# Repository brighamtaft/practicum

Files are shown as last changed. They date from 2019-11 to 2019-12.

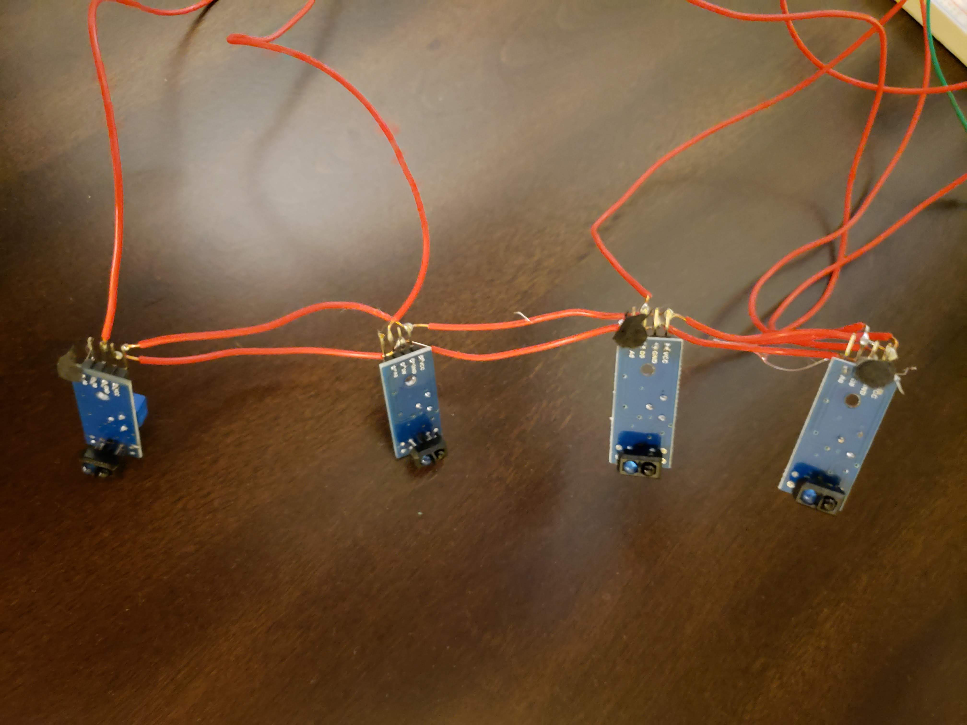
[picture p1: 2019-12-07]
sensors_prototype.jpg

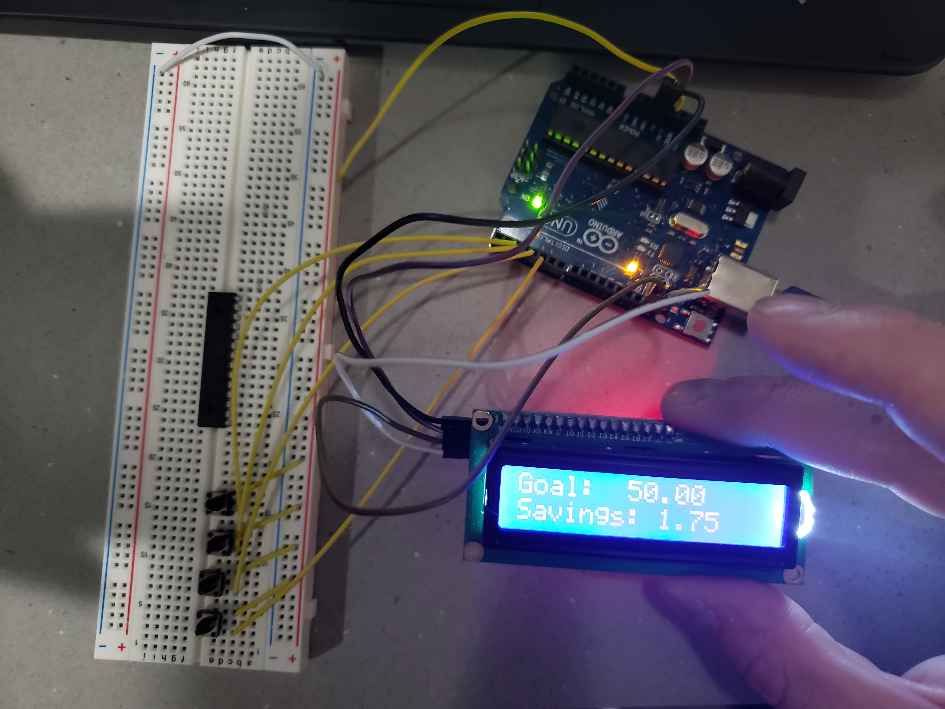
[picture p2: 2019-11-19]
prototype.jpg

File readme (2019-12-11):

(411RoughDraft.brd, 411RoughtDraft.sch) - status: complete - the 411roughDraft (.brd and .sch) are the original design files for our device. They are messy and error prone and do not hold any merit in the final design

(BOM.-Sheet1.pdf) - status: incomplete - Bill of Materials - has the appropriate quantity and compnents necessary for the PCB population but has yet to include the necessary materials needed for the container.

(BOM_Finalrev.xsl) - status complete - Bill of Materilas - up to date includes all necessary compoenents to be purchased.

(BankCode_rev1) - status: complete - The first complete rev for the arduino code used. Edit this to change the function of the microprocessor

(Child’s Piggy Bank.pptx) - status: incomplete - Presentation for final project that has in detail on what we did step by step 

(CointControllerV1.brd, CointControllerV1.sch) - status: complete - The complete schematic and brd layout for the device. Send the .brd file in to be printed.

(Coin Sort Face v5.stl, Coin Sort Ramp v5.stl) - status: complete but untested. These files have the same dimensions as the laser cut acrylic sorter and should work but have not been 3d printed and tested.

(TestPlan.pdf) - status: assignment comp[lete - test documentation with descriptions. Minimal test case in accordance with the assignment.

(Coin Sorter (Sized) v1.f3d) - status: complete but untested. This is a working 3D CAD file for fusion 360. It has been optimized to use minimum material and fit in a small print bed. It will require extensive supports to print with SLA style printer and would be recommended to split at the intersection of the ramp before printing in that style 3D printer.

(Design.pdf) - status: complete - basic block diagram of the basic functions of our device

(NextLevelDesign.pdf) - status: complete - a more detailed diagram of the functionality of our device

(PDS.docx) - status: complete - Product Design Specifications document

(ProjectBrainstorming.docx, Top.3.Ideas.docx) - status: complete - record of the project ideas for our group

(preliminarySchematicIMG.jfif, preliminarySchematic.sch) - status: complete - the very first incomplete basic schematic of device

(prototype.jpg) - status: complete - the first implemented device using buttons instead of sensors and an arduino

(testProcedure.docx) - status: incomplete - document describing the test procedure for the device

(T17 HW7 Test Plan.pdf) - status: complete - Homework based test plan.

(BetterSortV2.dxf) - status: Complete - Laser Printable file for acrylic coin sorter. Known to work with cast acrylic but not tested on other materials.

Programming instruction:
1) Flash the arduino bootloader onto the atmega328p. This can be done following the online tutorial found in this link: https://www.arduino.cc/en/Tutorial/ArduinoToBreadboard
2) Once the bootloader has been flashed you can solder the atmega328p to the board or insert it into a sleeve if you chose to purchase one.
3) Once the entire board is populated you can program the atmega328p with the BankCode_rev1 code. This can be done following the tutorial found at the same link as burning the bootloader. The difference in the connections is described below

Connections: (remember to remove the atmega328p from the arduinouno before programming)
  1) Arduino TX pin connects to pin5 of the 6x1 pin header
  2) Arduino RX pin connects to pin4 of the 6x1 pin header
  3) Arduino Vcc pin connects to pin2 of the 3x2 pin header
  4) Arduino gnd pin connects to pin6 of the 3x2 pin header
  5) Arduino reset pin connects to pin5 of the 3x2 pin header
  
 4) Once the wiring has been done upload the CoinCollector code to arduino as you normally would with the board selected being Arduino nano (atmega328p processor selected).
 5) The board should be ready to be wired up to the LCD screen and sensors. And you can begin the test procedure (see testProcedure.docx)

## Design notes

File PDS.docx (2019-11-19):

Product Design Specification (PDS)

Group 17

Brigham Webster

Jose Alvarez

Jens Evans

Sarah Mehler

Executive Summary / Concept of Operations

The Child’s Bank is a device that counts coins and displays the amount of money accrued. The bank is intended as a learning and motivation device for children, to help them keep track of how much money they have saved. To use the piggy bank, you put coins into the slot(s), and the bank automatically keeps a record of what has been entered.

Brief Market Analysis

The intended audience are parents who are interested in teaching their children about money. The competition would be conventional piggy banks. Our product is different because it not only helps children save money but also teaches them and is interactive. This will sell for about 20 dollars because the processing requirements are low which will require a simple chip. The device will also have a simple mechanical design for the coin storage that will be easily mass produced and batteries are sold separately.

Requirements

MUST

- Count coins (pennies, nickels, dimes, and quarters)
- Store Coins
- Be easy to use
- Display the amount of money that has been added in a clear and obvious way
- Use atmega328 processor
- Be PCB-based with 25% surface mount components

SHOULD

- Run on a battery
- Have an attractive enclosure
- Make the Mario coin sound when you insert a coin

MAY

- Sort coins
- Be able to set a goal
- Have a 3D printed animal-shaped enclosure

System Architecture

High Level Block Diagram

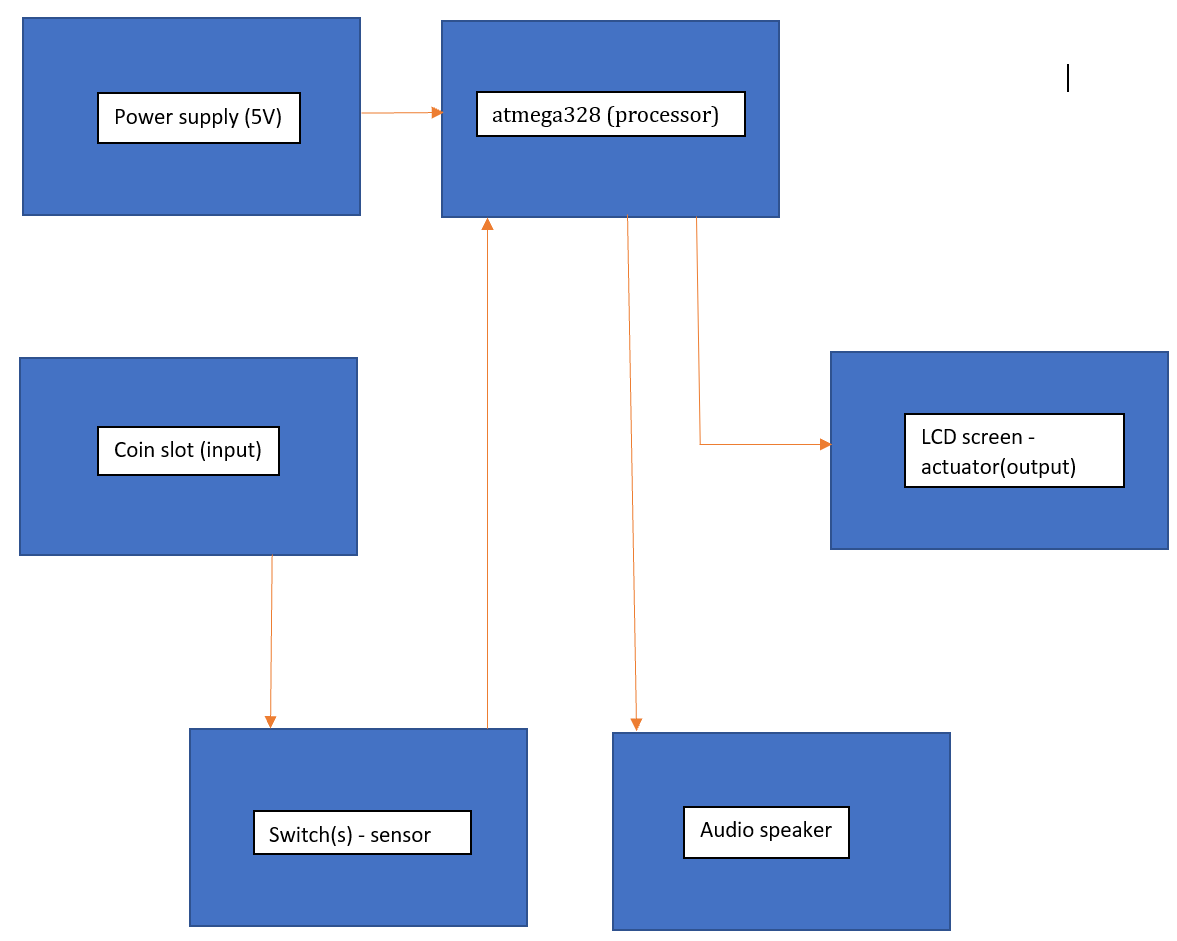
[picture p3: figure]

Design Specification

- The sensor will be a switch with enough sensitivity to be set by the weight of a coin.
- The processor will be an ATMEGA328
- The things that will be actuated are the inputs to the LCD screen
- The power supply will be about 5 Volts (Battery or USB)
- The mechanical design may be a wooden box with coin slots cut in and a lid to open it if we do not hit our must or may goals for a better box.
- We are going to use the Arduino development environment

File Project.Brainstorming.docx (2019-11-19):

Group 17

Sarah, Jose Alvarez, Jens, Brigham Webster

Brainstorming

1. Bike Computer (Speed or Cadence)
2. Electric Bike Motor
3. Hat that changes color for dancing at Rave******
4. Baby bottle temp sensor
5. Floating Business Card Holder****
6. Easy video game LED
7. Temperature sensor for phone (if it’s too hot or cold)
8. Timer you can set for how long you want to work (20 m, break, 20 m, etc.)
9. Cup thermometer tells you if coffee will burn your tongue****
10. Coin counter / piggy bank type device*****
11. Habit breaker
12. Habit MAKER / tracker
13. Fancy doorbell
14. Window security
15. Backup Beeper
16. Smart levelling device
17. Portable Charger
18. Short Range Transmitter Receiver
19. Wireless Morse Code Device
20. Optical Morse Code
21. Morse Code Decoder
22. Concussion Checker (Force for children)
23. Water bottle water measuring device
24. Wireless leash

Top 5 Ideas

Jens

1. Floating Business Card Holder (Levitating Magnet)
2. Piggy Bank
3. Electric Level
4. Bike Computer (Speed)
5. Device which can make any food

Brigham

1. Rave Hat
2. Seeing eye dog/backup car
3. Morse Code
4. Concussion Checker
5. Coin counter piggy bank

Sarah

1. Cup thermometer or baby bottle thermometer
2. Morse code device
3. Back up beeper
4. Coin counter / piggy bank
5. Level

Jose Alvarez

1. Portable charger
2. Morse code decoder
3. Wireless leash
4. Baby bottle temp sensor
5. Coin counter

Top 3 Ideas

1. Piggy Bank
2. Morse Code Decoder
3. Back up beeper

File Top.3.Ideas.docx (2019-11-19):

Practicum Top 3 Ideas

Group 17

Brigham, Sarah, Jens, Jose

1. Piggy Bank - group decided on the child's piggy bank for the practicum project

There will be different coin slots for quarters, dimes, nickels and pennies. Every time a coin is inserted into the appropriate slot a sensor will recognize this and count what has been inserted. An LCD display screen will display the current amount inside the bank which can be cleared/reset with a button. The atmega328 will control the LCD.

2. Morse Code Decoder

We will have a device that accepts input from a button in the form of morse code. The atmega328 will decode the morse and display it on an LCD screen.

3. Back up beeper

For cars that are outdated/not equipped with the back up rear view cameras or warning signals we will use a sensor that you can attach to the back of a car. It will produce a loud sound and light when the sensor gets within a certain range of an object. Additionally the light and sound frequency and intensity will increase as the sensor continues to move closer to an object. This is controlled by atmega328.

Conclusion: We chose the piggy bank because it sounded interesting to implement and had various challenges that all of has had not dealt with before. The piggy bank practicum idea can be easily divided into several components that can be easily split among the group. Additionally the piggy bank will not be so difficult that it would hinder our other lab projects and academic studies.

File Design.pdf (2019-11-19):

Brigham Webster
Jose Alvarez
Jens Evans
Sarah Muehler
Ece 411
Functional Decompposition

High Level Block Diagram

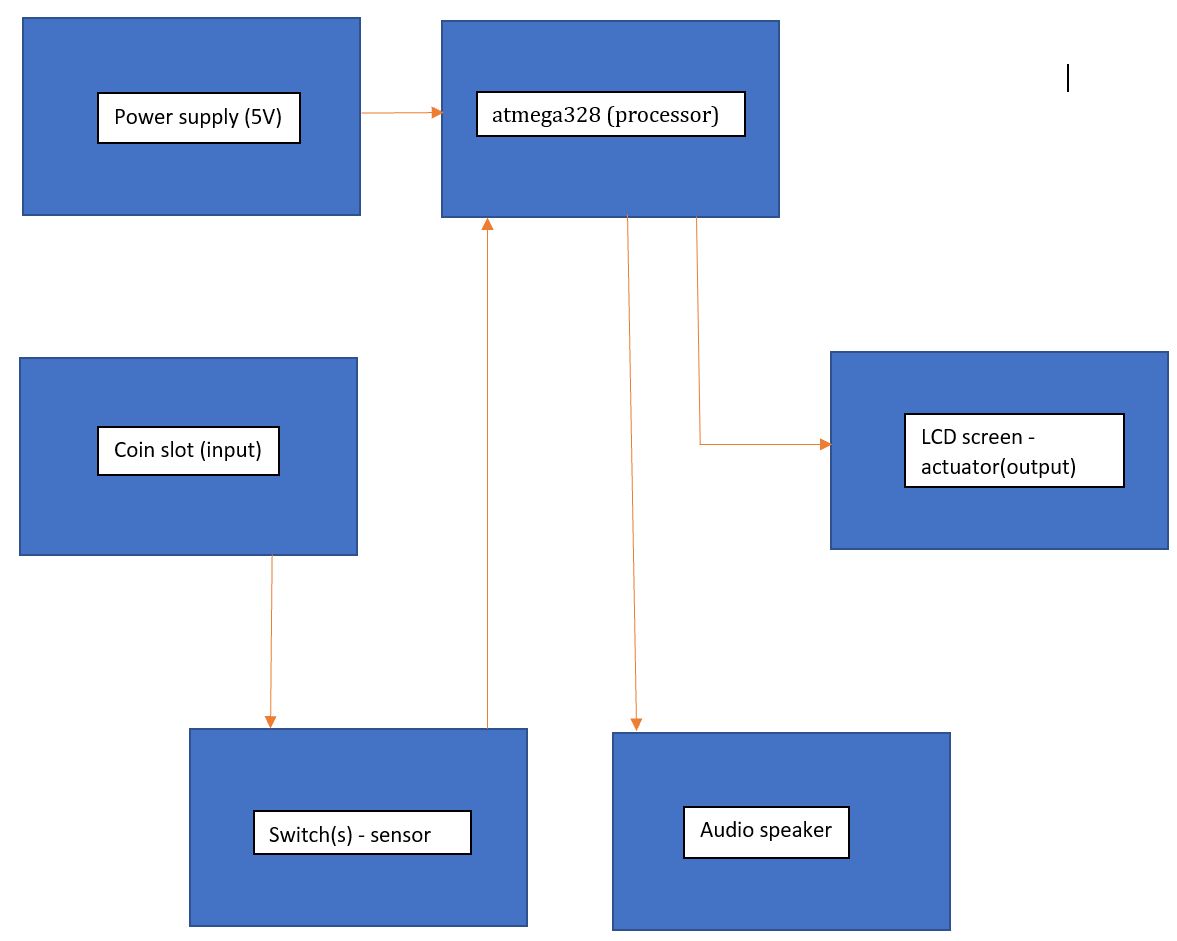
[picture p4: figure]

Next Level Block Diagram

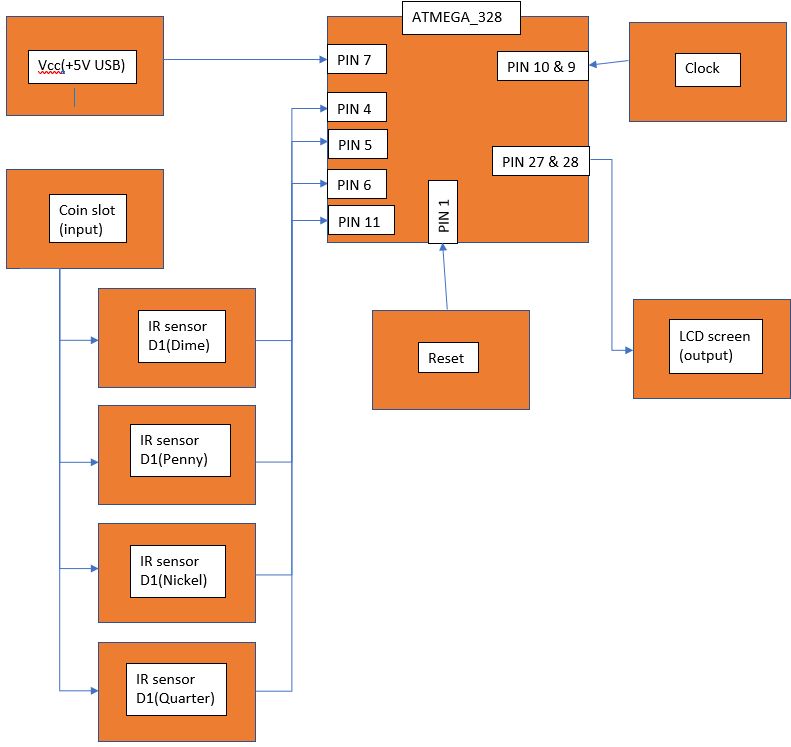
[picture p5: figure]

Microcontroller: Level 1

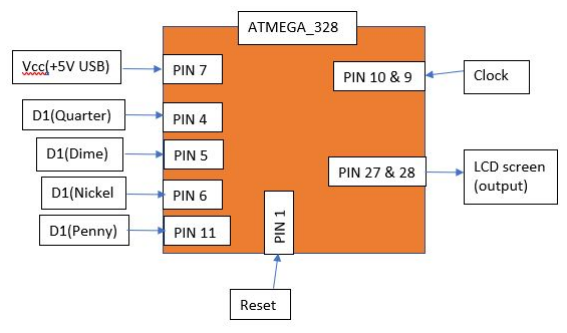
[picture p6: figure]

Module | Atmega328p
Inputs | 1. 5 Volt USB power supply (pin 7) 2. (4) IR Sensors detecting coin drop for quarter dime nickel penny (pins 4, 5, 6, 11 respectively) 3. Clock driving the atmega328p(pin 10, 9) 4. Reset Button
Outputs | 1. LCD Screen to communicate the data connected to the SCL and SDA of microcontroller. (pin 27 and 28)
Functionality | The brain of our device. Reads the input voltage from the sensor pins and depending on if they are high or low will add the corresponding value of currency associated with each pin to the total which will be displayed on the LCD screen.

IR Sensor Quarter: Level 1

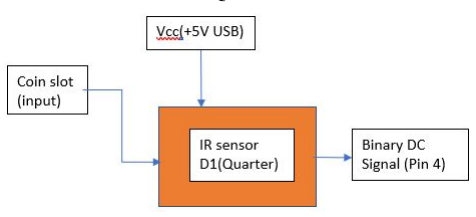
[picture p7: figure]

Module | IR Sensor D1 (Quarter)
Inputs | 1. 5 Volts USB power supply 2. Quarter Coin slot
Outputs | 1. IR sensor sends out a high or low voltage depending on the reading to pin 4 on the microcontroller.
Functionality | The sensors provide the data to the microcontroller. If a coin passes the sensor it sends out a logic high voltage value of 3 volts. Otherwise it stays constant at 0 Volts

IR Sensor Dime: Level 1

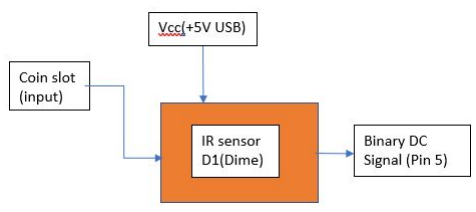
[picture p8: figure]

Module | IR Sensor D1 (Dime)
Inputs | 1. 5 Volts USB power supply 2. Dime Coin slot
Outputs | 1. IR sensor sends out a high or low voltage depending on the reading to pin 5 on the microcontroller.
Functionality | The sensors provide the data to the microcontroller. If a coin passes the sensor it sends out a logic high voltage value of 3 volts. Otherwise it stays constant at 0 Volts

IR Sensor Nickel: Level 1

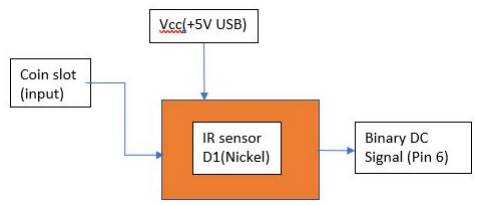
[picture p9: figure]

Module | IR Sensor D1 (Nickel)
Inputs | 1. 5 Volts USB power supply 2. Nickel Coin slot
Outputs | 1. IR sensor sends out a high or low voltage depending on the reading to pin 6 on the microcontroller.
Functionalit y | The sensors provide the data to the microcontroller. If a coin passes the sensor it sends out a logic high voltage value of 3 volts. Otherwise it stays constant at 0 Volts

IR Sensor Penny: Level 1

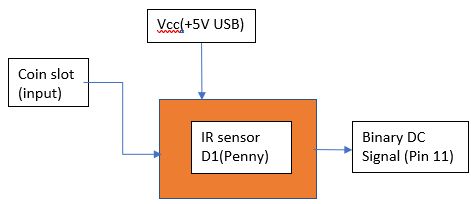
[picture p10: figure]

Module | IR Sensor D1 (Penny)
Inputs | 1. 5 Volts USB power supply 2. Penny Coin slot
Outputs | 1. IR sensor sends out a high or low voltage depending on the reading to pin 11 on the microcontroller.
Functionalit y | The sensors provide the data to the microcontroller. If a coin passes the sensor it sends out a logic high voltage value of 3 volts. Otherwise it stays constant at 0 Volts

Clock: Level 1

Module | Clock (16 MHz Crystal)
Inputs | 1. 5 Volts USB power supply
Outputs | 1. 16 MHz clock signal goes on pins 10 and 9
Functionalit y | The 16 MHz crystal drives the microcontroller functioning as the clock signal.

LCD Screen: Level 1

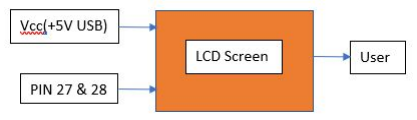
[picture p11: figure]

Module | LCD Screen
Inputs | 1. 5 Volts USB power supply 2. The SDA and SCL (pins 10 and 9) of the atmega328p
Outputs | 1. LCD screen displays the visuals read by the user.
Functionalit y | The LCD screen will display the goal savings amount as well as the current amount in the bank. Every time a coin is inserted the corresponding value will be added to the savings variable and that savings variable will be displayed on LCD.

Power Supply: Level 1

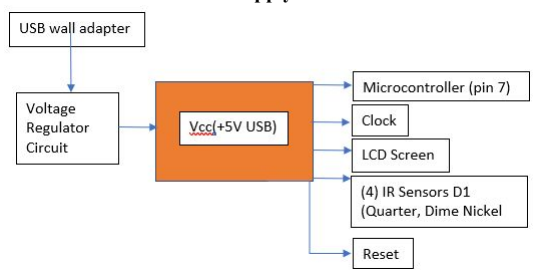
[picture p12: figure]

Module | Vcc(+5V USB)
Inputs | 1. USB wall adapter (5 Volt 2 Amp power supply)
Outputs | 1. IR Sensors D1 (Quarter, Dime, Nickel, Penny) 2. Microcontroller (pin 7) 3. LCD Screen 4. Clock 5. Reset Circuit
Functionalit y | Using just a simple wall adapter and USB cable as the input a simple voltage regulator circuit is used to set the +5V source. This 5 Volts source is then distributed across 8 devices in total. (4) identical IR Sensors, (1) microcontrontoller, (1) LCD Screen and the clock, (1) Reset Circuit and (1) Clock circuit.

Reset Circuit: Level 1

Module | Reset Switch
Inputs | 1. Gnd connection on one side of switch
Outputs | 1. Pin 1 on the microcontroller
Functionalit y | The reset function of the microcontroller is active low. So we tie the input of the reset pin (pin 1) to one end of the switch and to VCC. This way when the switch is pressed reset pin will go to 0 and the device will be reset.

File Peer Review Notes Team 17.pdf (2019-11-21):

Peer Reviews Detailed Notes
Jens Evans, Brigham Webster, Jose Alvarez, Sarah Mehler ECE 411 Practicum
Reviews by Andrew Greenburg and Jeff Roman

Comments in BOLD followed by actions taken to rectify the issue.

1. How are you terminating the pins. Do they need to be terminated? The pins which are not terminated have internal pull-up resistors.

### 2. We should consider adding an IDC connector for our daughter boards so that it can be

easily disconnected for construction purposes. We agree and will look into implementing this since it will work with the current design.
3. More stitching vias might be necesary. We doubled the amount of stitching vias.
4. You should take out the power jack if you are not going to use it. We chose to leave it knowing that it makes the board a little more complicated but adds flexibility for powering it.
5. +Vcc is not connected to anything so you need to rename nets. We renamed +Vcc nets to +5V so our schematic was consistent and all pins are correctly powered.
6. Make sure your team name, version and date are on your board. This has been fixed.
7. Pin a: capacitor to sound needs to be close to ground termination. The capacitor has been moved.

### 8. Rip up all ground routed wires that are unnecessary and use the ground plane to

accomplish this. We replaced all routed ground wires with a ground plane where possible.
9. Turn around USB connector and put it to a power trace. Both of these issues are fixed.
10. Add headers. Headers have been added.
11. Save after uploading OSH park design rules to get them to stay as default on this project. We did this.

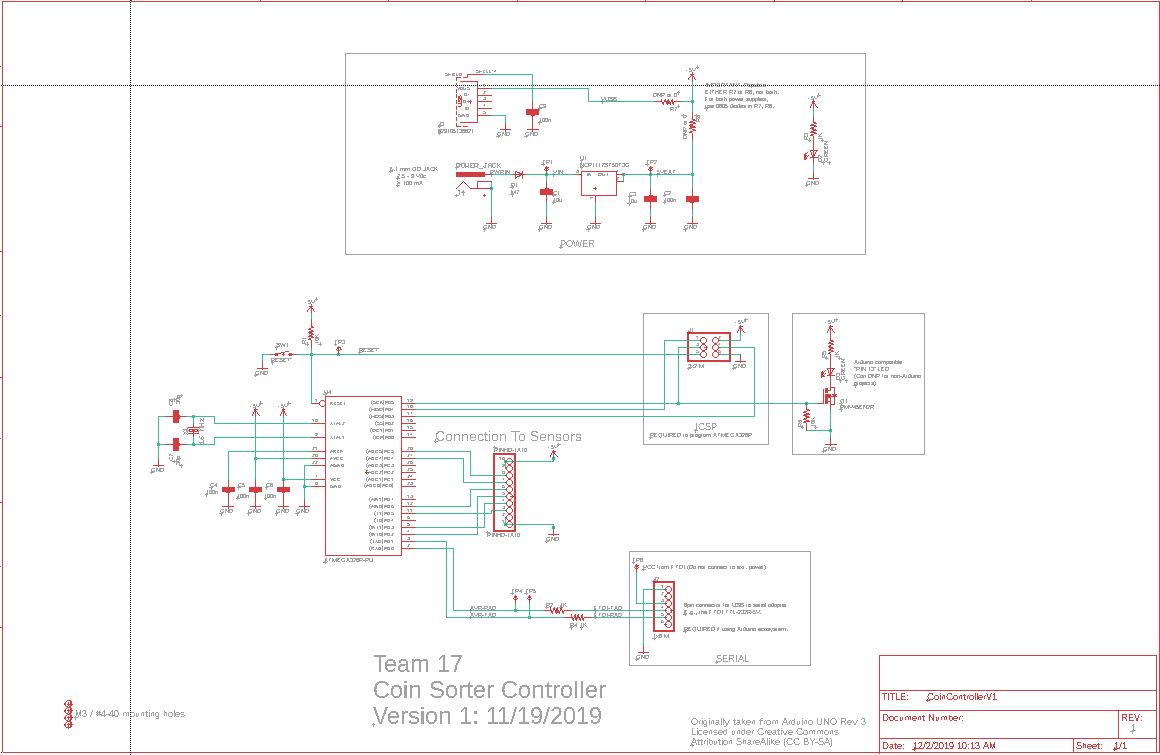
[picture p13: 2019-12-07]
final_schematic.JPG

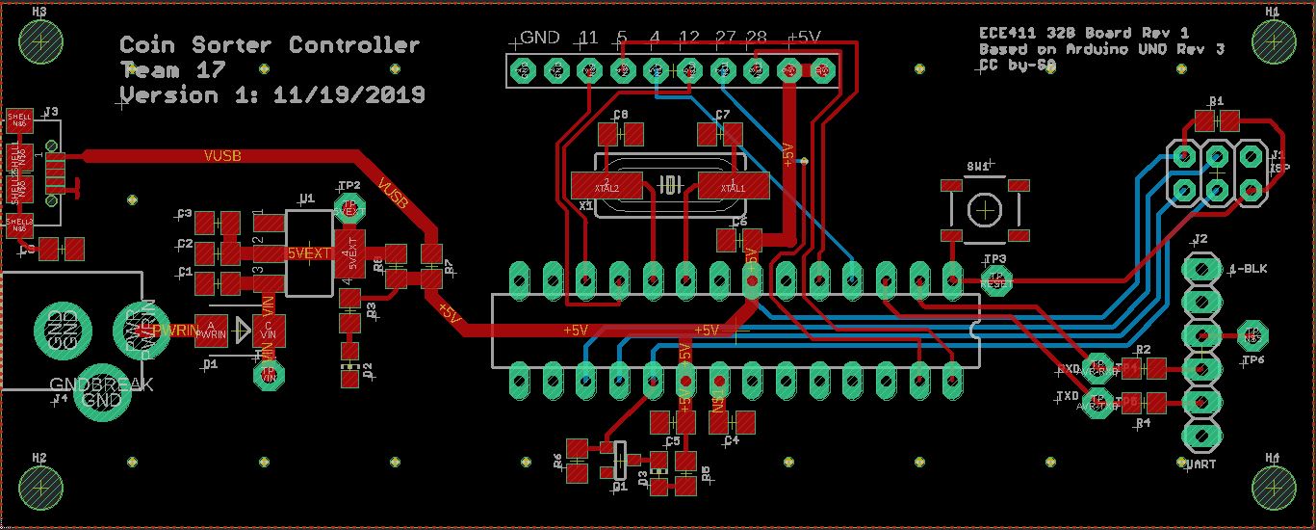
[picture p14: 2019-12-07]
FINAL_BOARD_LAYOUT.JPG

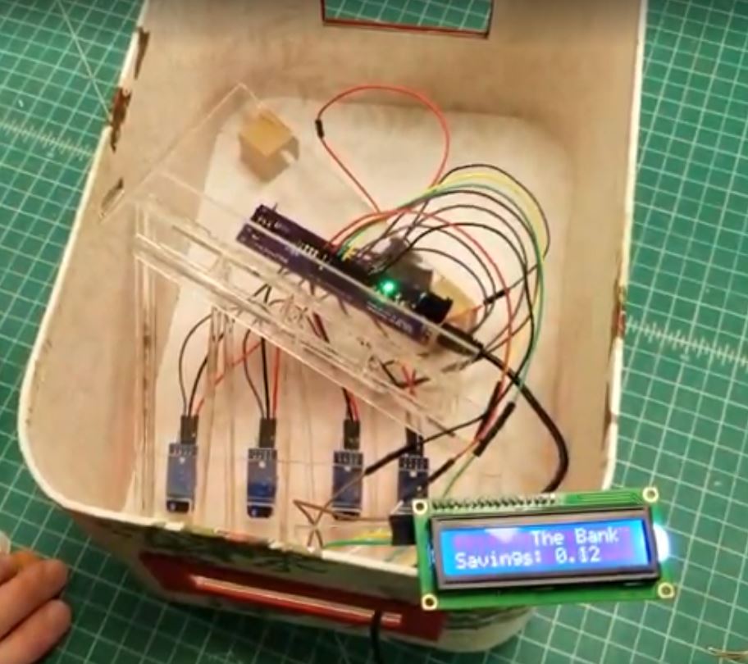
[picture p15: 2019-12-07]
prototypeModel.JPG

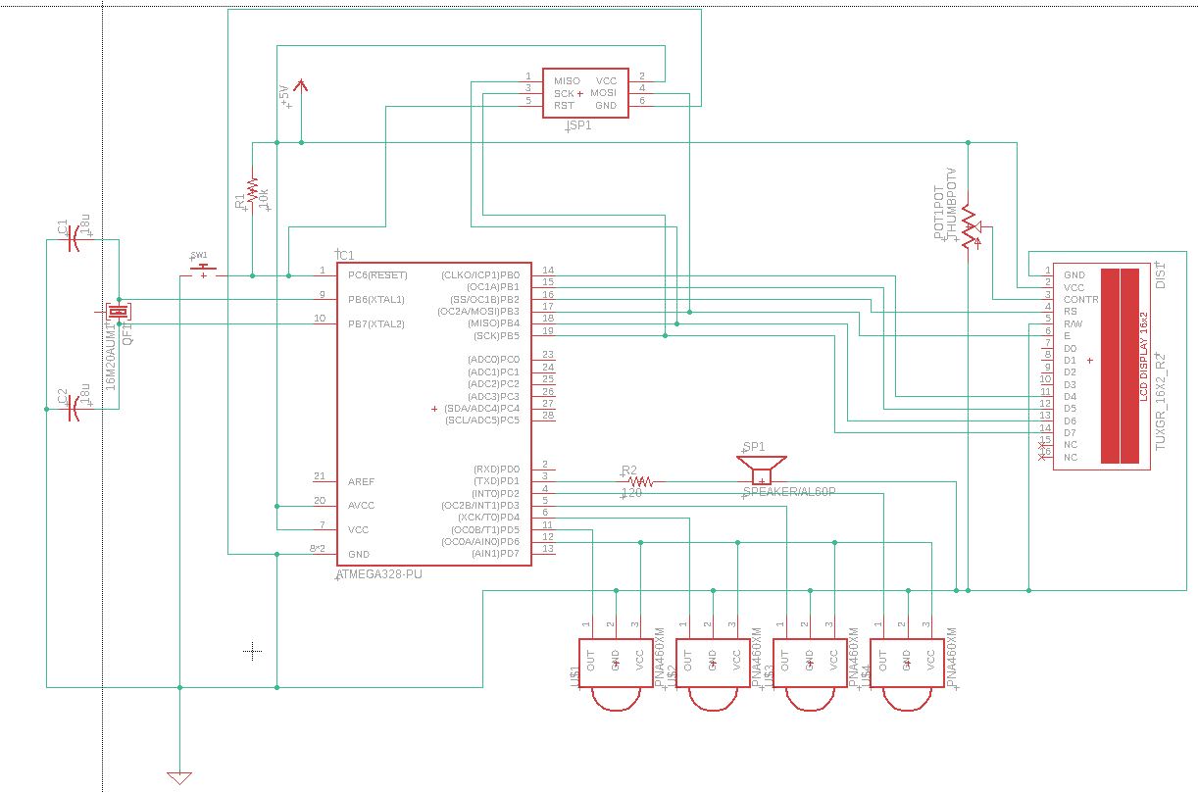
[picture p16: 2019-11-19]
Capture.JPG

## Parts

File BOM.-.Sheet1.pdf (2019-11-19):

Quantity | Reference Designator | Manufacturer | PN | Description
8 | C1, C3 | Samsung | CL21A106KOQNNNG | CAP CER 10UF 16V X5R 0805
20 | C2, C4, C5, C6, C9 | Samsung | CL21B104KBCNNNC | CAP CER 0.1UF 50V X7R 0805
8 | C7, C8 | Samsung | CL21C300JBANNNC | CAP CER 30PF 50V C0G/NP0 0805
4 | D1 | SMC Diode | 10BQ030TR | DIODE SCHOTTKY 30V 1A SMB
8 | D2, D3 | Würth Elektronik | 150080GS75000 | LED GREEN CLEAR 0805 SMD
4 | J1 | Harwin | M20-9980345 | CONN HEADER VERT 6POS 1 ROW 2.54MM
4 | J2 | Sullins | PRPC006SAAN-RC | CONN HEADER VERT 6POS 2 ROW 2.54MM
4 | J3 | Wurth | 629105136821 | CONN RCPT USB2.0 MICRO B SMD R/A
4 | J4 | CUI | PJ-202A | CONN PWR JACK 2X5.5MM KINKED PIN
4 | Q1 | Nexperia | PMV45EN2R | MOSFET N-CH 30V SOT23
8 | R1, R6 | Yageo | RC0805FR-0710KL | RES SMD 10K OHM 1% 1/8W 0805
16 | R2, R3, R4, R5 | Yageo | RC0805FR-071KL | RES SMD 1K OHM 1% 1/8W 0805
8 | R7, R8 | Yageo | RC0805JR-070RL | RES SMD 0 OHM JUMPER 1/8W 0805
4 | SW1 | C&K | RS-187R05A2-DS MT RT | SWITCH TACTILE SPST-NO 0.05A 12V
4 | U1 | ON Semiconductor | NCP1117ST50T3G | IC REG LINEAR 5V 1A SOT223
4 | U4 | Microchip | ATMEGA328P-PU | IC MCU 8BIT 32KB FLASH 28DIP
4 | X1 | ECS | ECS-160-18-5PX-TR | CRYSTAL 16.000 MHZ 18PF SMD
4 | J5 | Sullins Connector Solutions (https://www.digikey.com/en/supplier-centers/s/sullins-connector-solutions) | PPPC101LFBN-RC | Rectangular Connectors
4 | Connected to Pin 8, 7 of J5 | SunFounder | B019K5X53O | LCD 1602 16x2 Serial Interface Adapter Module
16 | Connected to pin 6, 5, 4, 3 of J5 | VISHAY | TCRT5000 | IR Reflective Sensor

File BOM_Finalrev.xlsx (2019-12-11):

Per Unit | Extended Price | Quantity | Reference Designator | Manufacturer | PN | Description
0.11 | 1.08 | 10 | C1, C3 | Samsung | CL21A106KOQNNNG | CAP CER 10UF 16V X5R 0805
0.05 | 1.02 | 20 | C2, C4, C5, C6, C9 | Samsung | CL21B104KBCNNNC | CAP CER 0.1UF 50V X7R 0805
0.06 | 0.60 | 10 | C7, C8 | Samsung | CL21C300JBANNNC | CAP CER 30PF 50V C0G/NP0 0805
0.06 | 0.24 | 4 | D1 | SMC Diode | 10BQ030TR | DIODE SCHOTTKY 30V 1A SMB
0.18 | 0.72 | 8 | D2, D3 | Würth Elektronik | 150080GS75000 | LED GREEN CLEAR 0805 SMD
0.27 | 1.08 | 4 | J1 | Harwin | M20-9980345 | CONN HEADER VERT 6POS 1 ROW 2.54MM
0.19 | 0.76 | 4 | J2 | Sullins | PRPC006SAAN-RC | CONN HEADER VERT 6POS 2 ROW 2.54MM
1.21 | 4.84 | 4 | J3 | Wurth | 629105136821 | CONN RCPT USB2.0 MICRO B SMD R/A
0.60 | 2.40 | 4 | J4 | CUI | PJ-202A | CONN PWR JACK 2X5.5MM KINKED PIN
0.43 | 1.72 | 4 | Q1 | Nexperia | PMV45EN2R | MOSFET N-CH 30V SOT23
0.04 | 0.36 | 10 | R1, R6 | Yageo | RC0805FR-0710KL | RES SMD 10K OHM 1% 1/8W 0805
0.04 | 0.59 | 16 | R2, R3, R4, R5 | Yageo | RC0805FR-071KL | RES SMD 1K OHM 1% 1/8W 0805
0.04 | 0.38 | 10 | R7, R8 | Yageo | RC0805JR-070RL | RES SMD 0 OHM JUMPER 1/8W 0805
0.25 | 1.00 | 4 | SW1 | C&K | RS-187R05A2-DS MT RT | SWITCH TACTILE SPST-NO 0.05A 12V
0.47 | 1.88 | 4 | U1 | ON Semiconductor | NCP1117ST50T3G | IC REG LINEAR 5V 1A SOT223
2.08 | 6.24 | 4 | U4 | Microchip | ATMEGA328P-PU | IC MCU 8BIT 32KB FLASH 28DIP
0.30 | 1.20 | 4 | X1 | ECS | ECS-160-18-5PX-TR | CRYSTAL 16.000 MHZ 18PF SMD
0.68 | 2.72 | 4 | J5 | Sullins Connector Solutions (https://www.digikey.com/en/supplier-centers/s/sullins-connector-solutions) | PPPC101LFBN-RC | Rectangular Connectors
5.00 | 20.00 | 4 | Connected to Pin 8, 7 of J5 | SunFounder | B019K5X53O | LCD 1602 16x2 Serial Interface Adapter Module
1.00 | 16.00 | 16 | Connected to pin 6, 5, 4, 3 of J5 | VISHAY | TCRT5000 | IR Reflective Sensor
12 | 48 | 4 | Sorter | EPL | N/A | Acrylic
12 | 48 | 4 | Container | EPL | N/A | Acrylic
 | 160.83
 | 40.2075

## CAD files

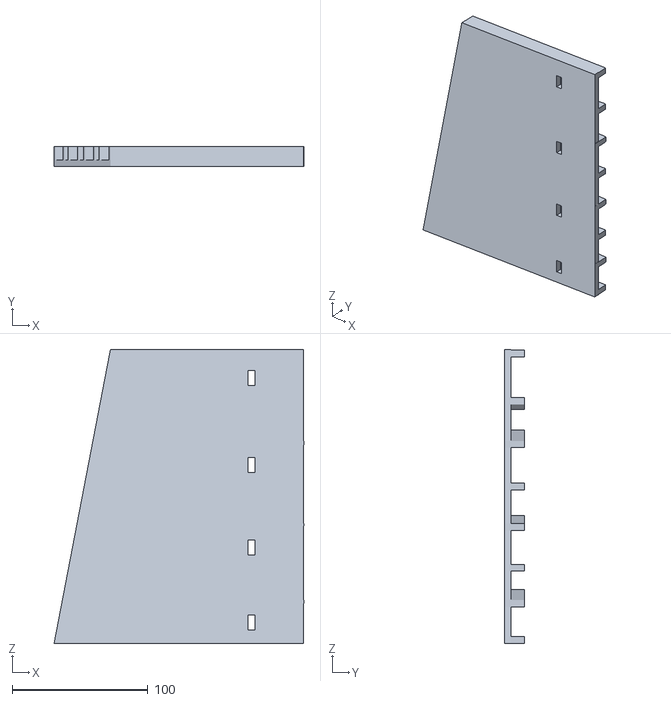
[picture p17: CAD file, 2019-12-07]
Coin Sort Ramp v5.stl
184.0 x 15.0 x 216.4

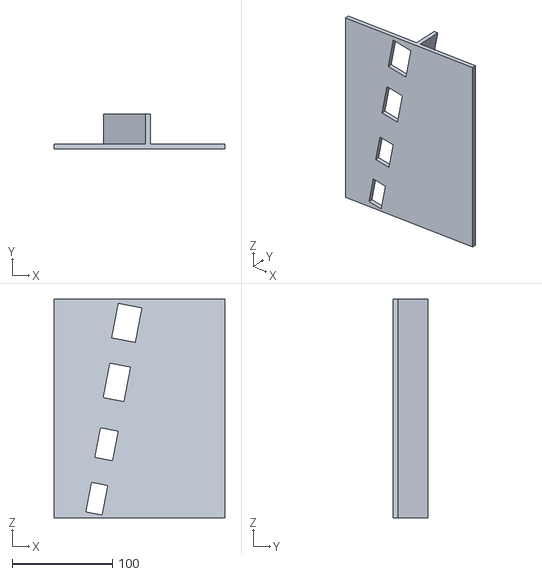
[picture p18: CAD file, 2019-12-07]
Coin Sort Face v5.stl
170.0 x 35.0 x 218.0

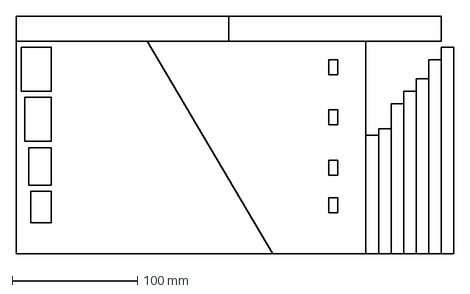
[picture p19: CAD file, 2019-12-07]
BetterSortV2.dxf
350.0 x 190.0 mm

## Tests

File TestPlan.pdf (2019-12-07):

Test Plan (Team Assignment) ECE 411 Fall 2019 Homework 7 Team 17: Jens Evans, Jose Alvarez, Sarah Mehler, Brigham Webster

PIGGY BANK DEVICE: System Test Plan

1.0 Introduction

2.0 Objectives and Tasks

2.1 Objectives

2.2 Tasks

3.0 Scope

4.0 Unit Testing

4.1 Software Verification

5.0 Functional Testing

5.2 Microcontroller

5.3 Sensor

5.4 Mechanical Sorter

6.0 Integration Testing

6.1 microcontroller & LCD via breadboard

6.2 (microcontroller & LCD) & Sensor via breadboard

6.3 (microcontroller & LCD) & Sensor on PCB

6.4 electrical and mechanical components

7.0 Acceptance Test

### 1.0 Introduction

The purpose of this test document is to provide thorough instruction on the test procedures required for the verification and acceptance of the Piggy Bank Device. This device will use a mechanical sorter to sort common U.S. change. The atmega328p microcontroller will read output from IR sensors and will keep track of how much change has entered the piggy bank.

### 2.0 Objectives and Tasks

### 2.1 Objectives

The objective of this test plan is to verify a working product. To accomplish this, a series of functional and integrative test procedures will be used to verify each component of the device. Once each stage of component testing has been completed there will be an integrative test that will integrate 1 additional component at a time. This will continue until all electrical components have been integrated and the final acceptance test will include the integration of the entire system (both electrical and mechanical).

### 2.2 Tasks

1. Successful Software Compile
2. Sensor Functionality Test
3. Mechanical Sorter Functionality Test
4. Integrate the Microcontroller and LCD Screen (on breadboard) Test
5. Integrate the Microcontroller and LCD Screen with Sensors (on breadboard) Test
6. Integrate the Microcontroller and LCD Screen andSensors on PCB Test
7. Integrate the Electrical Components with the Mechanical Components Test.
8. Product Acceptance Test

### 3.0 Scope

Code: The arduino code that will be uploaded to the microcontroller. This code is a loop that polls infrared sensors and increments coin values determined by which sensor was triggered. No additional functions exist and testing requires a simple compiling verification.

IR Sensors: The IR sensors send out an infrared signal and read the reflected value indicating motion. This functionality will need to be tested before integrated with the microcontroller

Microcontroller: The brain of the product. It reads the inputs from the sensors, and outputs to the LCD screen. Make sure that the code uploads to this microprocessor successfully. Build a simple breadboard circuit to run the microcontroller and use a verified LCD screen and switch interface to test the functionality of the microcontroller.

Mechanical Sorter: This is a series of holes cut to filter coins coins by their size. Once the coin falls in its specific slot it is guided over the sensor VIA a rail. Perform an exhaustive test to determine that the sorter will work for the specific coins consistently.

### 4.0 Unit Testing

This section focuses on the code functionality and successful compilation.

### 4.1 Software

This test is a verification of the code. You will use an arduino Uno and attempt to compile and upload the code to the arduino uno. The test is successful if the code compiles and uploads successfully.

### 5.0 Functional Testing

This section focuses on the functional verification of individual project components.

### 5.1 Sensor

Wire up the sensor with 5 volts supply and attach the output of the sensor to a digital multimeter. Pass an object (your hand) in front of the sensor. When the object comes within 1 cm of the sensor you should notice that the voltage reading of the digital multimeter is a high value (5 Volts). Once the object passes completely by the sensor there should be a 0 Volts reading on the digital multimeter. If the passing distance in front of the digital multimeter is more or less than 1 cm adjust the potentiometer on the sensor until the distance of detection is 1 cm.

Detailed Test Case Description for Functional Test 5.1

Test Writer: Team 17

Test Case Name: | Sensor Test | Test ID #: | ST_Rev1
Description: | Sensor Functional Test. Must be completed for all 4 sensors used in the device. | Type: | White Box

Test Information

Name of Tester: | | Date:
Hardware Ver: | 1.0 | Time:
Setup: | Ensure that system has been reset and total is $0.00
Step | Action | Expected Result | Pass | Fail | N/A | Comments

1 | Connect sensor VCC pin to 5 Volts source | N/A
2 | Connect sensor GND pin to ground of the 5 Volts source | Power indicator LED on all 5 sensors should be on.
3 | Connect the DO pin of the sensor to a digital multimeter who shares the same ground. | Multimeter should be reading 5 Volts.
4 | Pass an object in front of the sensor that is wired | 1. Green LED should light up. 2. Multimeter should be reading 0 Volts

Overall test result:

### 5.2 Mechanical Sorter

Exhaustively test that the corresponding Quarter, Dime, Nickel and Penny slide down the ramp and into the correct slot of the corresponding holes. Do 10 trials for each coin. If all trials go through the appropriate hole then it has passed.

### 6.0 Integration Testing

This section focuses on the functionality of verified components when integrated with one another.

### 6.1 microcontroller & LCD via breadboard

Program the atmega328p to display a dollar amount equal to the amount of money that has passed through the coin sorter. Place the atmega327 on the breadboard test circuit. Connect the 4 pins of the LCD to the RX, TX, GND and VCC pins of the atmega. Power on the circuit and confirm that the dollar amount display properly. Use the switches included in the breadboard circuit connected to pins 12, 11, 5, and 4. These will be the Quarter, dime, nickel and Penny pins respectively.

6.2 (microcontroller & LCD) & Sensor via breadboard

Using the breadboard test circuit, test whether triggering each of the 4 sensors with the appropriate voltage (5V) will produce the correct currency amount as displayed on the LCD screen.

6.3 (microcontroller & LCD) & Sensor on PCB
Using the PCB circuit, test whether triggering each of 4 sensors with the appropriate voltage will produce the correct currency amount. This can be done by passing any object in front of each sensor (finger is acceptable). Verify that the savings amount is updated accordingly.

Test Case Description for Integration Test 6.3

Test Writer: Team 17

Test Case Name: | Coin Test #1 | Test ID #: | CT_Rev1
Description: | Simulate inserting a quarter, dime, nickel, and penny with system integrated onto PCB. | Type: | Black Box

Test Information

Name of Tester: | | Date:
Hardware Ver: | 1.0 | Time:
Setup: | Make sure that system has been reset and LCD reads the amount $0.00.
Step | Action | Expected Result | Pass | Fail | N/A | Comments
1 | Simulate Inserting a Quarter | Screen should read $0.25

2 | Simulate Inserting a Dime | Screen should read $0.35
3 | Simulate Inserting a Nickel | Screen should read $0.40
4 | Simulate Inserting a Penny | Screen should read $0.41
5 | Power off, on | Screen should read $0.00

Overall test result:

### 6.4 electrical and mechanical components integration

This test is to be done on the With this completed system, insert three of each type of coin. Test whether, when each coin is inserted, the total displayed on the LCD screen increases by the appropriate amount. Additionally verify that the coins slide effortlessly and enter the correct slot every time.

### 7.0 Acceptance Test

The purpose of the acceptance test is to determine whether the product is acceptable to the client. In order to pass acceptance tests, the system must meet both functional and performance specifications. For the current system, the acceptance test will determine that the product is accurately recording the amount of change entered, that it is easy to use, and that it continues to function properly with repeated use.

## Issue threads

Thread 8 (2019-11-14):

Schematic & PCB Layout Rough Draft

brighamtaft, 2019-11-14:
We have errors pertaining to a straight edge on our design which we are trying to sort out.

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

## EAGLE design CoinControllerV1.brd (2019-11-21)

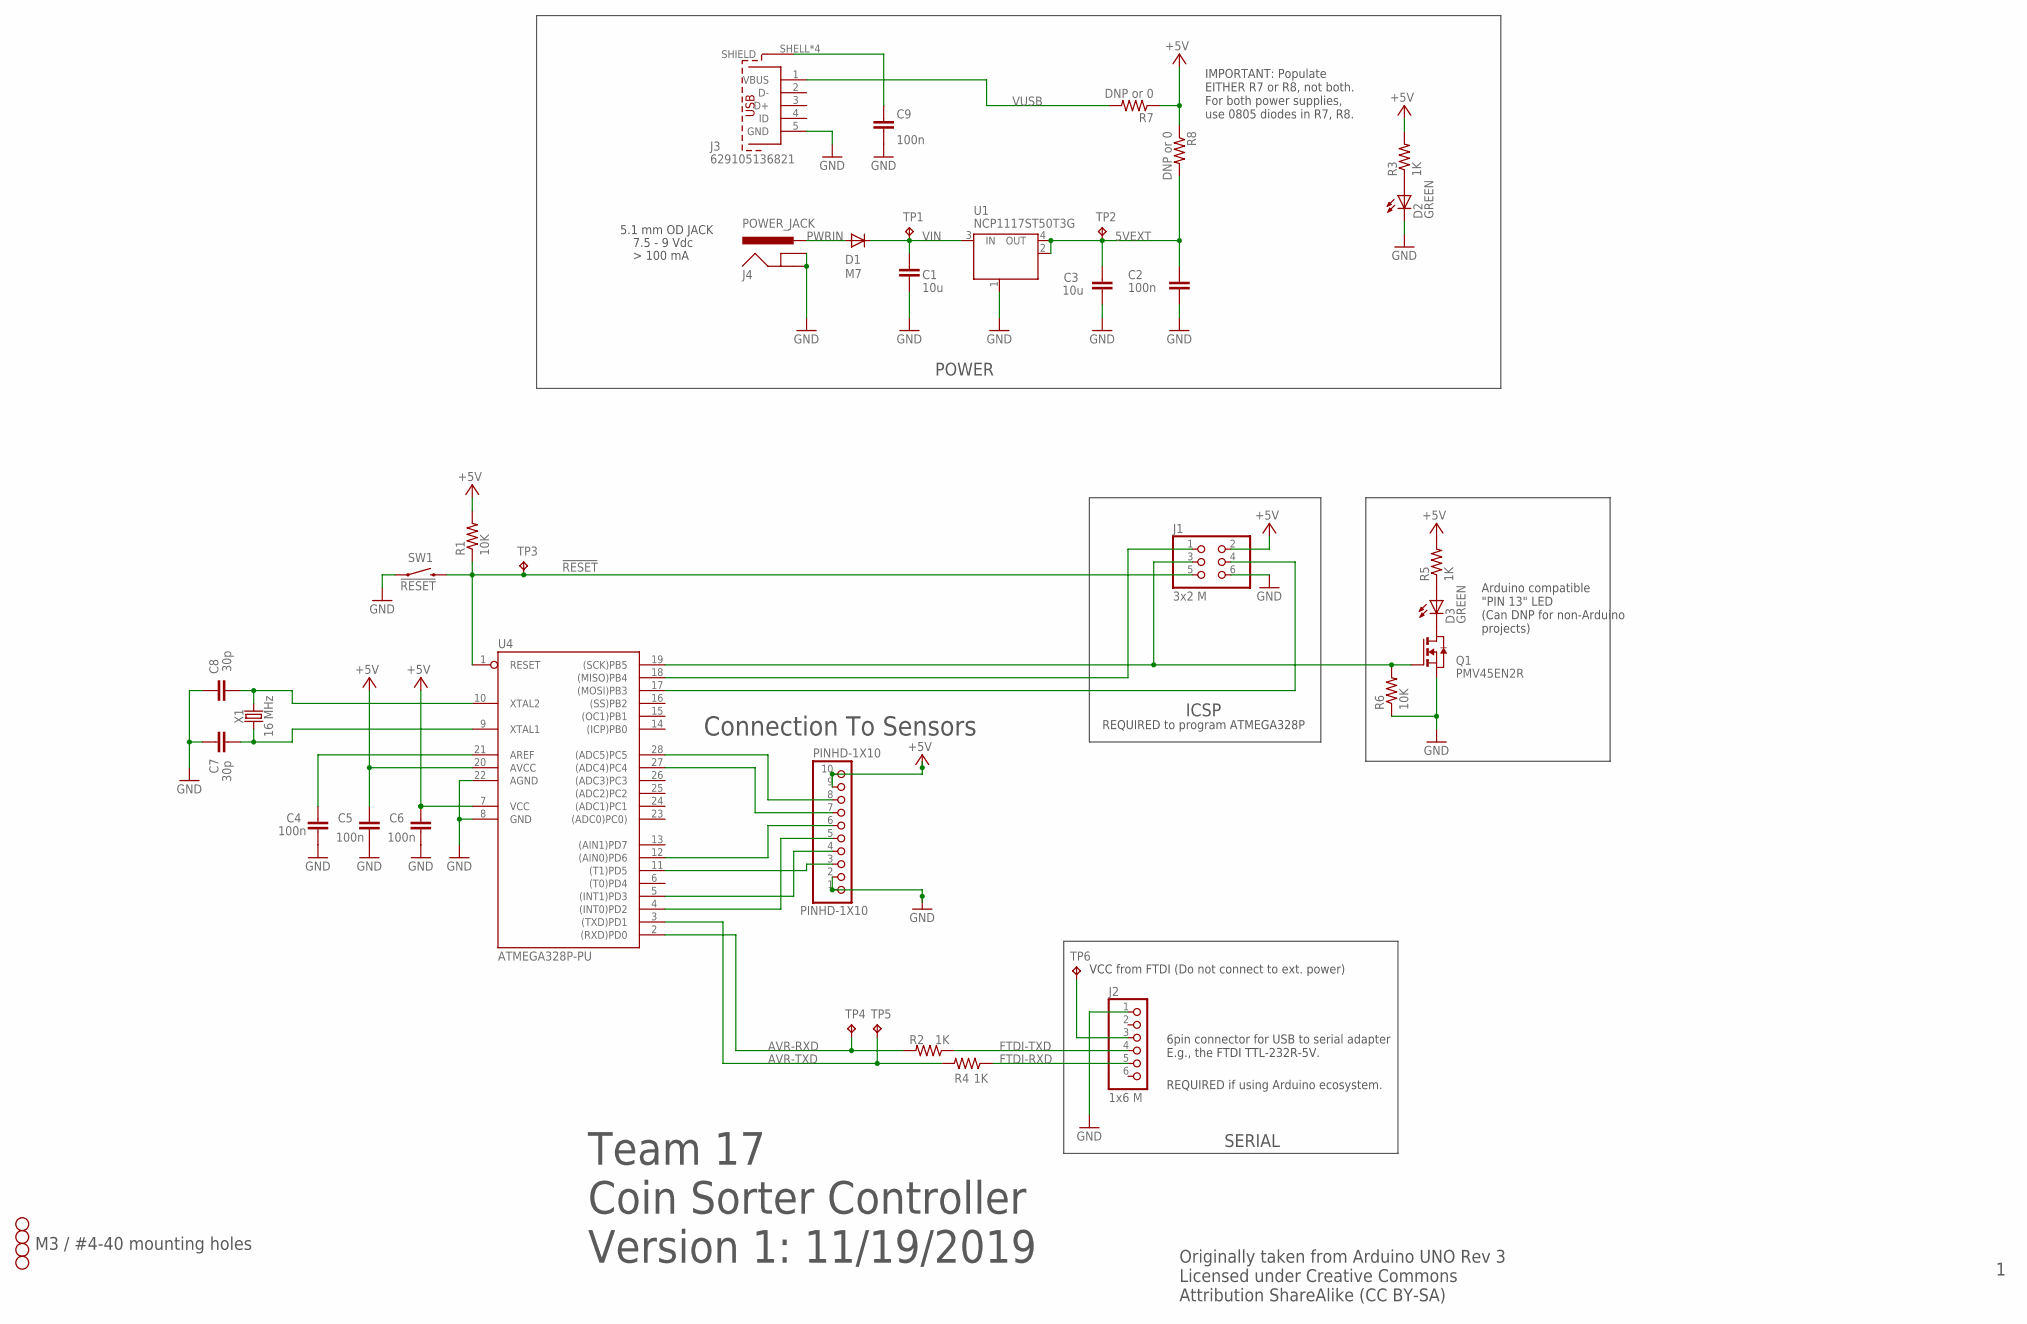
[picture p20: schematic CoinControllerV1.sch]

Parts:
C1, C3: 10u; C0805K; MPN CL21A106KOQNNNG
C2, C4, C5, C6, C9: 100n; C0805K; MPN CL21B104KBCNNNC
C7: 30p; C0805K; MPN CL21C180JBANNNC
C8: 30p; C0805K; MPN CL21C300JBANNNC
D1: M7; SMB; MPN 10BQ030TR
D2, D3: GREEN; CHIP-LED0805; MPN 150080GS75000
H1, H2, H3, H4: STAND-OFF
J1: 3x2 M; 2X03; MPN M20-9980345
J2: 1x6 M; 1X06; MPN PRPC006SAAN-RC
J3: 629105136821; MPN 629105136821
J4: POWER_JACK; POWER_JACK_PTH; MPN PJ-202A
PINHD-1X10: PINHD-1X10; 1X10-BIG
Q1: PMV45EN2R; SOT-23; MPN PMV45EN2R
R1, R6: 10K; R0805; MPN RC0805FR-0710KL
R2, R3, R4, R5: 1K; R0805; MPN RC0805FR-071KL
R7, R8: DNP or 0; R0805; MPN RC0805JR-070RL
SW1: !RESET; TACTILE_SWITCH_SMD; MPN RS-187R05A2-DS MT RT
TP1, TP2, TP3, TP4, TP5, TP6: TPPAD1-13; P1-13
U1: NCP1117ST50T3G; SOT223; MPN NCP1117ST50T3G
U4: ATMEGA328P-PU; DIL28-3; MPN ATMEGA328P-PU
X1: 16 MHz; HC49UP; MPN ECS-160-18-5PX-TR

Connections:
5VEXT: C2.2, C3.1, R8.2, TP2.TP, U1.2 (OUT), U1.4 (OUT)
!RESET: J1.5, R1.1, SW1.3 (2), TP3.TP, U4.1 (RESET)
+5V: C5.2, C6.2, J1.2, PINHD-1X10.9, PINHD-1X10.10, R1.2, R3.2, R5.2, R7.1, R8.1, U4.7 (VCC), U4.20 (AVCC)
AVR-RXD: R2.2, TP4.TP, U4.2 ((RXD)PD0)
AVR-TXD: R4.2, TP5.TP, U4.3 ((TXD)PD1)
FTDI-RXD: J2.5, R4.1
FTDI-TXD: J2.4, R2.1
GND: C1.2, C2.1, C3.2, C4.1, C5.1, C6.1, C7.2, C8.2, C9.1, D2.C, J1.6, J2.1, J3.5 (GND), J4.GND, J4.GNDBREAK, PINHD-1X10.1, PINHD-1X10.2, Q1.2 (S), R6.1, SW1.1, U1.1 (GND/ADJ), U4.8 (GND), U4.22 (AGND)
MISO: J1.1, U4.18 ((MISO)PB4)
MOSI: J1.4, U4.17 ((MOSI)PB3)
unnamed: C4.2, U4.21 (AREF)
unnamed: D3.A, R5.1
unnamed: D2.A, R3.1
unnamed: D3.C, Q1.1 (D)
unnamed: J2.3, TP6.TP
unnamed: C9.2, J3.SHELL (SHIELD), J3.SHELL1 (SHIELD), J3.SHELL2 (SHIELD), J3.SHELL3 (SHIELD)
unnamed: PINHD-1X10.5, U4.4 ((INT0)PD2)
unnamed: PINHD-1X10.4, U4.5 ((INT1)PD3)
unnamed: PINHD-1X10.3, U4.11 ((T1)PD5)
unnamed: PINHD-1X10.6, U4.12 ((AIN0)PD6)
unnamed: PINHD-1X10.7, U4.27 ((ADC4)PC4)
unnamed: PINHD-1X10.8, U4.28 ((ADC5)PC5)
PWRIN: D1.A, J4.PWR
SCK: J1.3, Q1.3 (G), R6.2, U4.19 ((SCK)PB5)
VIN: C1.1, D1.C, TP1.TP, U1.3 (IN)
VUSB: J3.1 (VBUS), R7.2
XTAL1: C7.1, U4.9 (XTAL1), X1.1
XTAL2: C8.1, U4.10 (XTAL2), X1.2

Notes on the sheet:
7.5 - 9 Vdc
POWER
ICSP
5.1 mm OD JACK
6pin connector for USB to serial adapter E.g., the FTDI TTL-232R-5V.
REQUIRED if using Arduino ecosystem.
M3 / #4-40 mounting holes
SERIAL
REQUIRED to program ATMEGA328P
Arduino compatible "PIN 13" LED (Can DNP for non-Arduino projects)
VCC from FTDI (Do not connect to ext. power)
IMPORTANT: Populate EITHER R7 or R8, not both. For both power supplies, use 0805 diodes in R7, R8.
Originally taken from Arduino UNO Rev 3 Licensed under Creative Commons Attribution ShareAlike (CC BY-SA)
Team 17 Coin Sorter Controller Version 1: 11/19/2019
Connection To Sensors

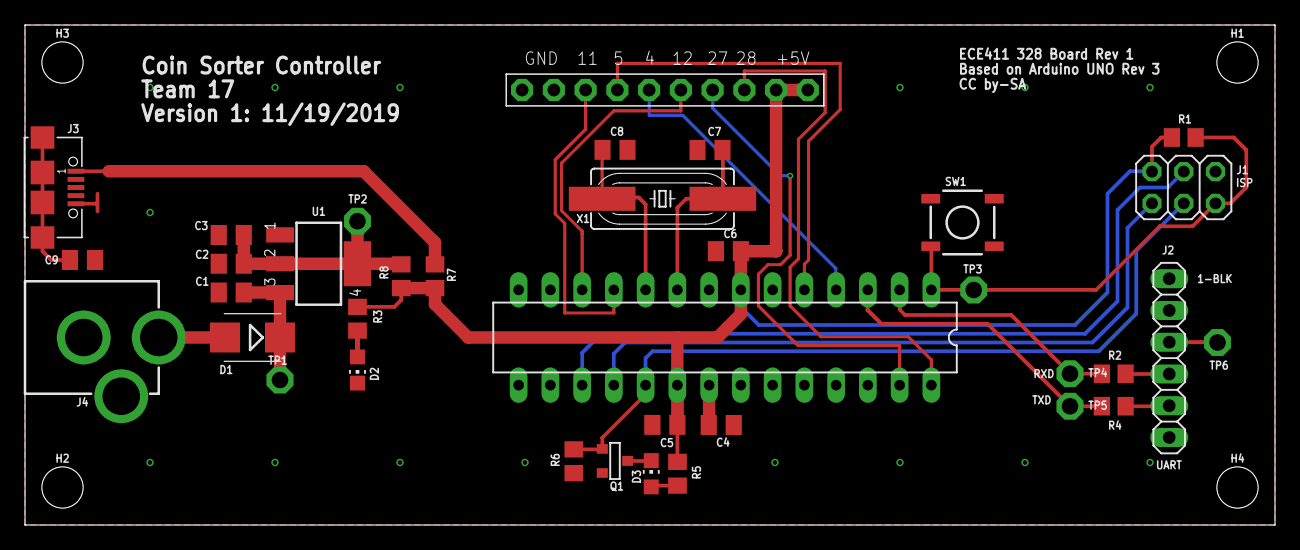
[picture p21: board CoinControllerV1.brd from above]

Board: 2 copper layers, 100.0 x 40.0 mm, 40 parts (0 on the bottom side), 28 nets.

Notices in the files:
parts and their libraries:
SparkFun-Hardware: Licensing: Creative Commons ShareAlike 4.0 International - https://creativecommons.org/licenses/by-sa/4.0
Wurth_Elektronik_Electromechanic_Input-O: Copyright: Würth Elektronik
